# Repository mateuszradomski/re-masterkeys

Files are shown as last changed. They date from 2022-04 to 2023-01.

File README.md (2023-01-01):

This repository aims to document the reverse engineering effort behind Cooler Master Masterkeys keyboards.

As a result you can:
 - re-flash the original firmware with a different key map
 - flash QMK [see here](https://github.com/mateuszradomski/qmk_masterkeys)
 - write your own bare metal firmware

Currently **only the Masterkeys Pro S White** is tested and proved working.
If you have any other keyboard from this series you can contribute by expanding the current knowledge.
Checkout the work of [hansemro](https://github.com/hansemro) in the Issues Tab right now.
Everything from this point on is written from the point of view of the Pro S White.

# Hardware specification

The keyboard contains three ICs:

 - Holtek HT32F52352 ARM MCU (the chip is probably mislabeled as HT50F52352 [see](https://github.com/pok3r-custom/pok3r_re_firmware/issues/32))
 - GigaDevice GD25Q40C 4MB SPI Flash
 - Macroblock MBIA043GP LED Driver

The MCU is a 48MHz ARM Cortex-M0+ chip.
[ChaoticEnigma](https://github.com/ChaoticEnigma) has already compiled a list of documentation PDFs and examples from Holtek in the [pok3r_re_firmware](https://github.com/pok3r-custom/pok3r_re_firmware) repo.
You are going to see a lot of references to the work of [ChaoticEnigma](https://github.com/ChaoticEnigma), without his RE efforts this probably would not be possible.
Thanks!
The MCU is inside a 64 pin package and almost all of them are used.
The board contains a JTAG connector that will be crucial in flashing your own firmware.
From the start it's locked but you can unlock it which allows you to read/write to it freely.
You can find the pin-out for the JTAG in the schematic stored in the `kicad` directory.
Ground is the pin closest to the MCU, while VDD is the furthest pin from the MCU.
If you feel unsure about it, you can always use a multimeter to confirm.

The SPI is used in the original firmware to store profiles - accessed via `FN + 1-4`.
You can use it in your own firmware if you need, the documentation is inside the `docs` directory, but you can easily find it on the internet.

The LED driver has 16 output pins, it's used in combination with 8 pins from the MCU to form a matrix.
Positive voltage is emitted by the driver to a particular column and the LED will glow if the row has been pulled low by the MCU.
Because of the amazing work done by [hansemro](https://github.com/hansemro) in RE of lighting for Pro S RGB which shares the same chip with Pro S White, lighting is now supported in QMK.
The documentation for the chip does not really exist but many things are similar across the chips, for general hang of how the chip work checkout the documentation to MBI5040 in the docs folder.
And for special instructions that are supported by the MBIA043GP see the accompanying .md file, information there is copied from hansemro's issue for the Pro S RGB model.

# Original firmware

_I do not take responsibility for any damages that you might make to your keyboard while trying to anything with it_

From the three Pro X White variants only Pro M and Pro L have firmware upgrades.
This makes the process of recovering the original Pro S White firmware hard.
Cooler Master hosts these updates [here for Pro M](http://update.coolermaster.com/masterkeys-pro-m-white/masterkeys-pro-m-white-v1.06.zip) and [here for Pro L](update.coolermaster.com/masterkeys-pro-l-white/masterkeys-pro-l-white-v1.08.zip).
Using the [pok3rtool](https://github.com/pok3r-custom/pok3rtool) you can extract the firmware from these updaters which has [already been discussed in this issue](https://github.com/pok3r-custom/pok3rtool/issues/6).

If you plan to flash your own firmware and your bootloader is not currently inside the `binaries` directory, I advise to flash a modified version of the firmware with the flash reading patch.
It's pretty well described in the issue linked above.
After patching and dumping the `bootloader + firmware` you are more or less safe - meaning if you manage to brick your keyboard you can reprogram it using any JTAG debugger or Raspberry Pi, I used the Raspberry Pi Zero which worked a treat.
You if you dumped a bootloader from a different model your contribution is welcomed!

## Pro S White note

Since firmware for this keyboard is not provided by Cooler Master currently it's not possible to re-flash back to stock firmware.
You can use Pro L firmware and modify - using a hex editor - the key map which brings your keyboard back to a working condition.
As a side effect **lighting no longer works**!
If you want to modify the key map it's defined as an array of USB-HID codes starting at offset `0x618d` in the Pro L firmware file.
In the `binaries` directories I attached a Pro L firmware with the Pro S keymap - Caps is Escape right now.

# Flashing

## The role of the original bootloader

The keyboard has essentially two programs on it: bootloader and firmware.
Firmware is what is running on it most of the time, everything from lighting to profiles are implemented there.
The thing I refer to as a bootloader is an in-application programming (IAP) program.
It allows you to reprogram the firmware without having to use the JTAG connector every time.
So if you want to quickly iterate over firmwares I'd suggest leaving the bootloader be.

You have two options of flashing:

## Erase the original bootloader and program every time using the JTAG

If you want to need more flash memory you can remove the original bootloader which takes around 12.5Kb (~10% of the flash).
It's almost never the case you want to do this so move to the second option.

## Use the bootloader to write the new firmware using the pok3rtool

The already mentioned [pok3rtool](https://github.com/pok3r-custom/pok3rtool) is perfect for flashing the new firmware.

If you stick to the original firmware and only make small tweaks it will put the keyboard in to the bootloader mode for you and reprogram it.

On the other hand if you use QMK you can set your keyboard so that it will boot into the bootloader.
This is already done in the linked QMK, just press `LShift + RShift + B`.
Your keyboard will boot into the bootloader and await being programmed.
You can confirm this by watching the output `dmesg`, it should appear as a `Cooler Master HID-IAP`.
When it's ready flash the firmware.

## Example flashing using the bootloader

 - Download [pok3rtool](https://github.com/pok3r-custom/pok3rtool)
 - Apply the patch referencing your keyboard from `patches`
 - Compile the tool
 - Run `sudo ./pok3rtool --ok -t cmpro<s|m|l> flash <version string> <your firmware binary>`
 - Your keyboard is flashed!
 
# Unlocking the MCUs JTAG

[ChaoticEnigma](https://github.com/ChaoticEnigma) already figured this out [here](https://github.com/pok3r-custom/pok3r_re_firmware/wiki/HT32-Unlocking).
His fork of the OpenOCD with the HT32F1xxxx support works with HT32F5xxxx MCUs as well.
Remember that the logic of the keyboard works on `3.3V`!
If you want to be extra careful not to fry anything just connect all cables without VDD and power the keyboard by connecting it to USB.

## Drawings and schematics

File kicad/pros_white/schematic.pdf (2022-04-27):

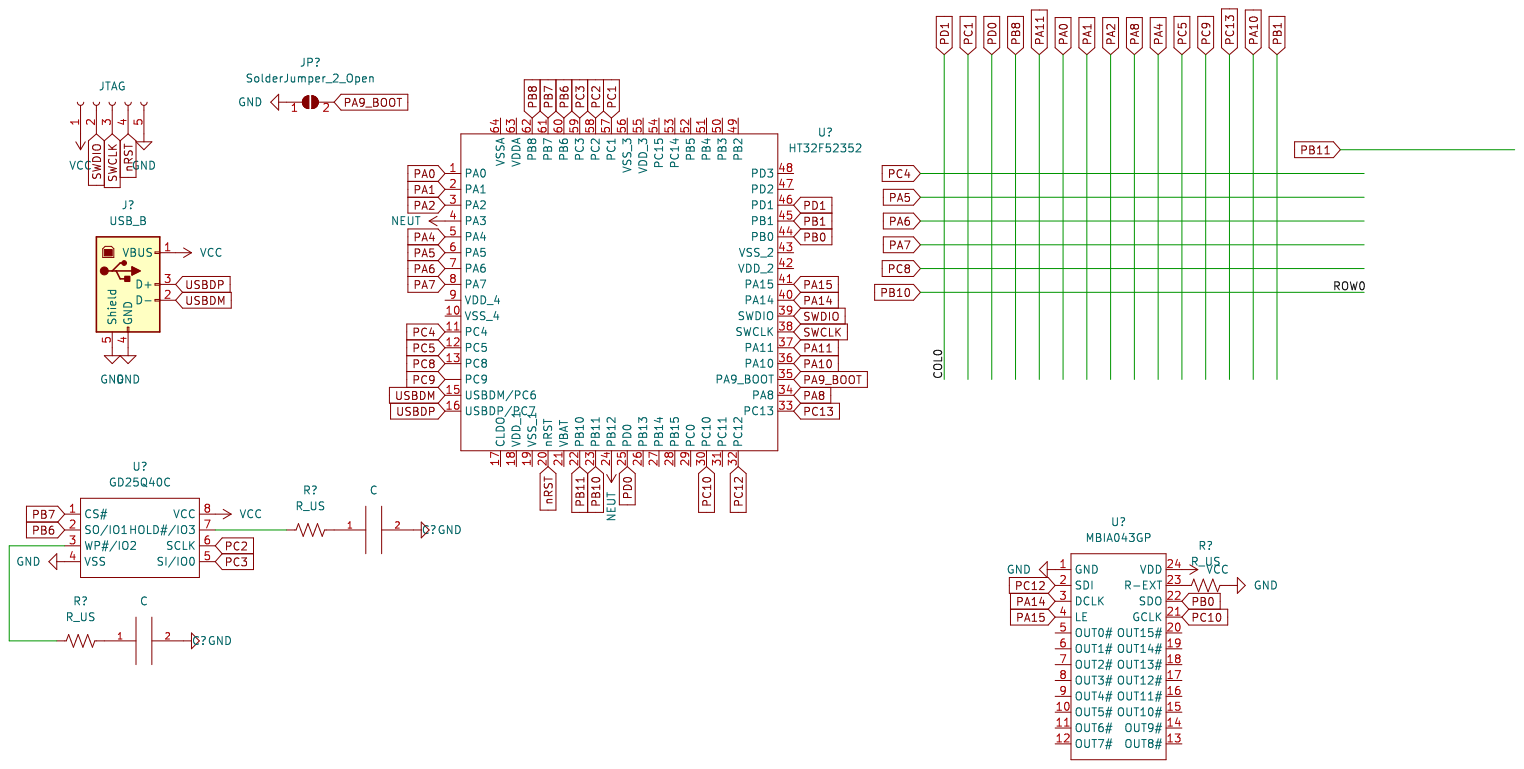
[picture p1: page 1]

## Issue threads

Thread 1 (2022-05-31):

Pro S RGB Support

hansemro, 2022-05-31:
I was unable to find detailed specs anywhere else for this model, so here is what I found:
- Holtek HT32F1654 (Cortex-M3)
- GigaDevice 25Q40CT
- 3x Macroblock MBIA043GP (1 per channel)

CN2 header:
- pin 1: 3v3
- pin 2: SWDIO
- pin 3: SWCLK
- pin 4: nRST
- pin 5: GND

SEL1 header:
- pin 1: BOOT0
- pin 2: GND

SEL2 header:
- pin 1: GND
- pin 2: BOOT1

So far, very similar to POK3R RGB. I will update with more details as I find them.

Tasks:
- [ ] Add photos
- [ ] Add Pro S RGB schematic
- [ ] Access JTAG
- [ ] Try unlocker
- [ ] Dump SPI flash
- [ ] Dump bootloader and firmware
- [ ] Write to flash
- [ ] TODO

hansemro, 2022-06-01:
Raspberry Pi 4 : ProS
- pin 9 : GND
- pin 12 : nRST
- pin 18 : SWDIO
- pin 22 : SWCLK

Rebased openocd-ht32 with latest commits to fix some issues with raspberry pi: https://github.com/hansemro/openocd-ht32/tree/ht32f165x-dev

openocd.cfg:
```
adapter driver bcm2835gpio
adapter speed 1

### for pi4
bcm2835gpio peripheral_base 0xFE000000
bcm2835gpio speed_coeffs 236181 60

## swd_nums <swclk> <swdio>
## Header pins 22 18
bcm2835gpio swd_nums 25 24

## reset: pin 12 on the PI
bcm2835gpio srst_num 18
reset_config srst_only srst_push_pull

## dont forget pin 9 for Ground

transport select swd

set HT32_SRAM_SIZE 0x8000
set HT32_FLASH_SIZE 0x20000

source [find target/ht32f165x.cfg]
```

```
pi@raspberrypi:~ $ sudo openocd
Open On-Chip Debugger 0.11.0+dev-02293-g1f3300cca (2022-06-01-06:21)
Licensed under GNU GPL v2
For bug reports, read
        http://openocd.org/doc/doxygen/bugs.html
trst_only separate trst_push_pull

Info : Listening on port 6666 for tcl connections
Info : Listening on port 4444 for telnet connections
Info : BCM2835 GPIO JTAG/SWD bitbang driver
Info : clock speed 12 kHz
Info : SWD DPIDR 0x2ba01477
Info : [ht32f165x.cpu] Cortex-M3 r2p0 processor detected
Info : [ht32f165x.cpu] target has 6 breakpoints, 4 watchpoints
Info : starting gdb server for ht32f165x.cpu on 3333
Info : Listening on port 3333 for gdb connections
```

hansemro, 2022-06-01:
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

hansemro, 2022-06-02:
Pro S RGB firmware patch: https://github.com/hansemro/re-masterkeys/blob/Pro_S_RGB/binaries/Pro_S_RGB/patch.txt

```
FW offset 0x3400 (?)

    67fa: ff 28           cmp        r0,#0xff
    67fc: 0c d1           bne        0x00006818
    67fe: 68 68           ldr        r0,[r5,#0x4]
    6800: 3c 21           movs       r1,#0x3c
    6802: 31 e0           b          0x00006868
    6804: 00 bf           nop
    6806: 00 bf           nop
    6808: 00 bf           nop
    680a: 00 bf           nop
    680c: 00 bf           nop
    680e: 00 bf           nop
    6810: 00 bf           nop
    6812: 00 bf           nop
    6814: 00 bf           nop
    6816: 00 bf           nop
```

hansemro, 2022-06-02:
Some USB packet captures:

1: Plugging in keyboard
[plug-in.zip](https://github.com/m-radomski/re-masterkeys/files/8823571/plug-in.zip)

2: Firmware upgrade (1.2.2 to 1.2.2) via OEM software
[fw-upgrade.zip](https://github.com/m-radomski/re-masterkeys/files/8823574/fw-upgrade.zip)

hansemro, 2022-06-02:
python script to get current firmware from Pro S:

Dependency: pyusb

get_version.py:
```
#!/usr/bin/env python3

import usb.core
import usb.util

dev = usb.core.find(idVendor=0x2516, idProduct=0x003c)

if dev is None:
    raise ValueError('CM Pro S not found')
else:
    print("CM Pro S found")

if dev.is_kernel_driver_active(1):
    try:
        dev.detach_kernel_driver(1)
        print("kernel driver detached")
    except usb.core.USBERROR as e:
        print(f"Could not detach kernel driver: {e}")
        exit(1)

try:
    usb.util.claim_interface(dev, 1)
    print("Claimed usb device")
except:
    print(f"{e}")
    exit(1)

ver_req = [ 0x01,0x02,0xdf,0xfc,0x00,0x30,0x00,0x00,0x3d,0x30 ]

dev.write(0x04, ver_req)

out = dev.read(0x83, 64)
out = "".join(chr(x) for x in out)
print(f"{out[4:9]}")
```

output:
```
$ python3 get_version.py
CM Pro S found
kernel driver detached
Claimed usb device
1.2.2
```

hansemro, 2022-06-03:
Reset to bootloader: `[0x4,0x1]`
Reset to firmware: `[0x4,0x0]`

hansemro, 2022-06-04:
Analyzing fw-upgrade.pcap from above.

un: unknown
ar: address
ct: count
pd: padding
ed: end

Start writing firmware at 0x3400 in 0x34 byte increments...

```
       write-un-un-ar.ar.ar.ar-ed-ct-pd-pd-_data...
0000   01 01 2a 4b 00 34 00 00 33 34 00 00 _48 27 00 20
0010   55 35 00 00 61 35 00 00 63 35 00 00 65 35 00 00
0020   67 35 00 00 69 35 00 00 00 00 00 00 00 00 00 00
0030   00 00 00 00 00 00 00 00 6b 35 00 00 6d 35 00 00
```

0x34 (52,+0x34) bytes written
expect next data to be written start with 0000 0000 6f35...
next_write_addr: 0x3434

```
0000   01 01 c9 af 34 34 00 00 67 34 00 00 _00 00 00 00
0010   6f 35 00 00 71 35 00 00 73 35 00 00 73 35 00 00
0020   73 35 00 00 73 35 00 00 73 35 00 00 73 35 00 00
0030   73 35 00 00 73 35 00 00 73 35 00 00 73 35 00 00
```

0x34 (+0x68) bytes written
expected next data: 7335 0000 7335 0000 7335 ....
next_write_addr: 0x3468

```
0000   01 01 ae 41 68 34 00 00 9b 34 00 00 _73 35 00 00
0010   73 35 00 00 73 35 00 00 73 35 00 00 73 35 00 00
0020   73 35 00 00 73 35 00 00 73 35 00 00 73 35 00 00
0030   73 35 00 00 73 35 00 00 73 35 00 00 73 35 00 00
```

0x34 (+0x9c) bytes written
next_write_addr: 0x349c

```
0000   01 01 b2 e2 9c 34 00 00 cf 34 00 00 _73 35 00 00
0010   73 35 00 00 73 35 00 00 00 00 00 00 73 35 00 00
0020   73 35 00 00 73 35 00 00 73 35 00 00 73 35 00 00
0030   73 35 00 00 73 35 00 00 73 35 00 00 73 35 00 00
```

0x34 (+0xd0) bytes written
next_write_addr: 0x34d0

```
0000   01 01 e3 0c d0 34 00 00 03 35 00 00 _73 35 00 00
0010   00 00 00 00 00 00 00 00 00 00 00 00 00 00 00 00
0020   e1 37 00 00 8d 38 00 00 73 35 00 00 73 35 00 00
0030   73 35 00 00 73 35 00 00 73 35 00 00 73 35 00 00
```

0x34 (+x01_04) bytes written
next_write_addr: 0x3504

```
0000   01 01 5f 7d 04 35 00 00 37 35 00 00 _73 35 00 00
0010   73 35 00 00 73 35 00 00 73 35 00 00 bd 85 00 00
0020   00 00 00 00 73 35 00 00 73 35 00 00 73 35 00 00
0030   73 35 00 00 73 35 00 00 73 35 00 00 73 35 00 00
```

0x34 (+x01_38) bytes written
next_write_addr: 0x3538

```
0000   01 01 28 9b 38 35 00 00 6b 35 00 00 _73 35 00 00
0010   00 00 00 00 00 00 00 00 00 00 00 00 00 00 00 00
0020   00 00 00 00 73 35 00 00 07 48 80 47 07 48 80 47
0030   07 48 00 47 fe e7 fe e7 fe e7 fe e7 fe e7 fe e7
```

Need help figuring out what the two unknown bytes are.
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
hansemro, 2022-09-09:
Fixed firmware writing with my fork of pok3rtool with https://github.com/hansemro/pok3rtool/commit/11b822daccf6230801e9e4c1574e27bc54f884a1, managed to dump flash from another Pro S RGB, and recover my previously dead board with stock bootloader!

hansemro, 2022-09-14:
Added initial schematic drawing after a few days of tracing: https://github.com/hansemro/re-masterkeys/commit/35a5ebbd49aea75002c9e5f61e1f66275bda403c

hansemro, 2022-10-06:
Added initial QMK support (key switch and USB support only): https://github.com/hansemro/qmk_firmware/tree/prosrgb_dev

hansemro, 2022-10-11:
# MBIA043 RE notes:

These results were discovered from firmware disassembly and testing in QMK.

## Instructions
Instructions are determined by the number of DCLK rising edges while LE is asserted.

For instructions that read data from shift register, the falling edge of LE must occur after the final data entry gets shifted.

### Data Latch: 1 DCLK rising edge

Moves data from shift register to buffer.

### Overall Latch: 2 DCLK rising edges

Sets comparator to value in buffer.

### (Undocumented) Read Configuration: 4 DCLK rising edges

Moves 10-bit configuration data to shift register.

Configuration:
```
  MSB     ...     LSB
0b0_0_0_0_0_0_0_0_1_0 (default)
  | | | | | | | | | `-> counter disable (when 1)
  | | | | | | | | `-> unk1
  | | | | | | | `-> unk2
  | | | | | | `-> unk3
  | | | | | `-> unk4 (cannot be set)
  | | | | `-> unk5 (cannot be set)
  | | | `-> unk6 (cannot be set)
  | | `-> unk7 (cannot be set)
  | `-> unk8
  `-> unk9 (cannot be set)
```

### (Undocumented) Enable Write Configuration: 18 DCLK rising edges

Enables Write Configuration instruction (if it is the next instruction).

### (Undocumented) Write Configuration: 8 DCLK rising edges

Moves data from shift register to (undocumented) configuration register.

hansemro, 2022-10-14:
Dimming test (shortened cycle length to reduce video length) with QMK.

https://user-images.githubusercontent.com/40348686/195756326-3854ea60-c413-4904-a0f4-0d8b56e75f63

hansemro, 2022-10-17:
Per-key lighting on QMK:
https://user-images.githubusercontent.com/40348686/196301393-073a03fa-a6db-4df2-932d-af04cba0297b.mp4

hansemro, 2022-10-24:
Keyboard (with QMK) hardfaults after enabling Flash Memory Security Protection bit (OB_PP[0]).

hansemro, 2022-11-14:
Added a new openocd branch to enable security bits (which will be used to debug lockup when security is enabled): https://github.com/hansemro/openocd-ht32/tree/ht32f165x-security-test

```
> # unlocked keyboard
> halt; ht32f165x check_security 0
[ht32f165x.cpu] halted due to debug-request, current mode: Handler External Interrupt(41)
xPSR: 0x21000039 pc: 0x00000108 msp: 0x20000d18
ht32f165x probe: 128 pages, 0x400 bytes, 0x20000 total
ht32f165x opt byte: ffffffff ffffffff ffffffff ffffffff ffffffff
ht32f165x CPSR: 0xffffffff
ht32f165x OB_CP: 0xffffffff
ht32f165x OB_CK: 0xffffffff
ht32f165x opt byte: ffffffff ffffffff ffffffff ffffffff ffffffff
ht32f165x check_security complete

# relocking keyboard
> halt; ht32f165x enable_security 0
[ht32f165x.cpu] halted due to debug-request, current mode: Handler External Interrupt(41)
xPSR: 0x01000039 pc: 0x00000134 msp: 0x20000d28
ht32f165x probe: 128 pages, 0x400 bytes, 0x20000 total
ht32f165x opt byte: ffffffff ffffffff ffffffff ffffffff ffffffff
ht32f165x programming word 0x0000 @ 0x1ff00000
ht32f165x programming word 0xffffffff @ 0x1ff00004
ht32f165x programming word 0xffffffff @ 0x1ff00008
ht32f165x programming word 0xffffffff @ 0x1ff0000c
ht32f165x programming word 0xfffffffe @ 0x1ff00010
ht32f165x programming word 0xfffffffb @ 0x1ff00020
ht32f165x Security will be set on reset
ht32f165x enable security complete

# confirming keyboard is locked
> halt; ht32f165x check_security 0
[ht32f165x.cpu] halted due to debug-request, current mode: Handler HardFault
xPSR: 0x01000003 pc: 0x00000124 msp: 0x20000d28
ht32f165x probe: 128 pages, 0x400 bytes, 0x20000 total
ht32f165x opt byte: 0000 0000 0000 0000 0000
ht32f165x CPSR: 0xfffffffc
ht32f165x OB_CP: 0x0000
ht32f165x OB_CK: 0x0000
ht32f165x opt byte: 0000 0000 0000 0000 0000
ht32f165x check_security complete
```

hansemro, 2022-11-14:
While keyboard is locked, things you can do in openocd:
- use `reset halt` command to halt MCU in working state before it faults.
- set registers (e.g. `reg <r0|r1|...|pc> <value>`) and `step` through instructions while in working state.
- read registers with `reg` command

Some things you cannot do while locked:
- Use load instructions to read data from internal program flash (DCODE). Load instructions in firmware will read in 0 (while debugger is attached). Loading from SRAM (0x20000000) works just fine.

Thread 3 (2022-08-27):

Pro L RGB Support

hansemro, 2022-08-27:
HW info: TODO

Tasks:
- [ ] Add photos
- [ ] Add schematic
- [ ] Write firmware patch
- [ ] Patch pok3rtool
    - [ ] Add Pro L RGB VID/PID/IPID
        - [ ] firmware mode : 2516:0047
        - [ ] bootloader mode : 2516:0046
    - [ ] version command
    - [ ] setversion command
    - [ ] reboot command
    - [ ] bootloader command
    - [ ] info command
    - [ ] dump command
    - [ ] flash command
    - [ ] wipe command
- [ ] Working firmware patch
- [ ] Dump firmware
- [ ] Dump bootloader
- [ ] Dump SPI flash

hansemro, 2022-08-27:
Info command output:
```
$ ./pok3rtool -t prolrgb info --ok
Opened MasterKeys Pro L RGB
3000  12000000 56003100 2e003000 38002e00 30003000 0000ffff ffffffff ffffffff | ....V.1...0.8...0.0.............
3020  ffffffff ffffffff ffffffff ffffffff ffffffff ffffffff ffffffff ffffffff | ................................
3040  ffffffff ffffffff ffffffff ffffffff ffffffff ffffffff ffffffff ffffffff | ................................
3060  ffffffff ffffffff ffffffff ffffffff ffffffff ffffffff 04008000 00030100 | ................................
3080  41000000 ffffffef 01000000 00000000 d9046701 ffffffff ffffffff ffffffff | A.................g.............
30a0  ffffffff ffffffff ffffffff ffffffff a55a1c00                            | .................Z..    
Version String: V1.08.00
a: 00800004
Version: 00010300
c: 00000041
d: efffffff
e: 00000001
f: 00000000
VID/PID: 04d9 0167
h: 001c5aa5
READ_400
0000  04000000 00000000 16254600 00000404 ffffffff 01000000 ffffffff 2e000000 | .........%F.....................
0020  0002e700 00024b42 30313933 00000000 ffffffff                            | ......KB0193........    
READ_3c00
0000  04000200                                                                | ....                    
true
```

hansemro, 2022-08-27:
Setting custom version:
```
$./pok3rtool -t prolrgb version
Opened MasterKeys Pro L RGB
Version: V1.08.00
$ ./pok3rtool -t prolrgb --ok setversion V1.07.FF
Opened MasterKeys Pro L RGB
Old Version: V1.08.00
Reset to Bootloader
Writing Version: V1.07.FF
1
Reset to Firmware
true
$ ./pok3rtool -t prolrgb version
Opened MasterKeys Pro L RGB
Version: V1.07.FF
```

hansemro, 2022-08-27:
Just realized that I have White model lol. Didn't even bother to check if it was RGB.

hansemro, 2022-08-27:
Modified SVD: [HT32F52342_52.svd.zip](https://github.com/mateuszradomski/re-masterkeys/files/9438735/HT32F52342_52.svd.zip)

SVD Source: https://web.archive.org/web/20220827045212/https://mcu.holtek.com.tw/pack/Holtek.HT32_DFP.1.0.41.pack

hansemro, 2022-08-28:
I was able to dump bootloader and firmware with this updated patch:

```
FW offset 0x3200

        6260: ff 28           cmp        r0,#0xff
        6262: 05 d1           bne        0x00006270
        6264: 68 68           ldr        r0,[r5,#0x4]
        6266: 3c 21           movs       r1,#0x3c
        6268: 30 e0           b          0x000062cc
        626a: 00 bf           nop
        626c: 00 bf           nop
        626e: 00 bf           nop
```

Flashing patched firmware with patched pok3rtool worked without a hitch:
```
$ git clone https://github.com/hansemro/re-masterkeys -b Pro_L_White
$ cd re-masterkeys/binaries/Pro_L_White
$ pok3rtool -t prolwhite flash V1.09.00 ProLW_fw_patched.bin --ok
Opened MasterKeys Pro L White
Update Firmware: ProLW_fw_patched.bin
Reset to Bootloader
Current Version: V1.08.00
Firmware CRC D: 2519525c
Firmware CRC E: 4edec2ee
crc 3d198f21
sum e3f6fbbb
Current CRC: 3d198f21
Erase...
Write...
crc 4edec2ee
sum e400cc6d
New CRC: 4edec2ee
Writing Version: V1.09.00
Reset to Firmware
true
$ pok3rtool -t prolwhite dump bl_fw_dump.bin --ok
Opened MasterKeys Pro L White
Dump Flash
Out: bl_fw_dump.bin, 65520 bytes
```

hansemro, 2022-10-27:
Added initial schematic drawing in KiCad: https://github.com/hansemro/re-masterkeys/blob/09ef6fb995ffd5092bbb7bde4db733936313a8f0/kicad/prol_white/25L4006E.kicad_sym

hansemro, 2022-10-28:
WIP QMK with MBI5042 demo (source coming soon):

https://user-images.githubusercontent.com/40348686/198546031-cec75729-407e-4fda-baa9-234bb24be269.mp4

@mateuszradomski Were you able to map led pins on Pro S White? This should be easy to replicate on Pro S White with MBIA043 drivers that I wrote for Pro S RGB.

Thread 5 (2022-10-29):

Pro M White Support

hansemro, 2022-10-29:
HW info:
- Holtek HT32F52352 (Cortex-M0+)
- Macroblock MBI5042GP LED Driver

Tasks:
- [ ] Add photos
- [ ] Add schematic
- [ ] Write firmware patch
    - [ ] Find FW offset: 0x3200 (based off VTOR offset)
- [x] Patch pok3rtool: WIP fork https://github.com/hansemro/pok3rtool/tree/cooler-master-dev
    - [x] Add Pro M White VID/PID/IPID
        - [x] firmware mode : 2516:0048
        - [x] bootloader mode : 2516:0049
    - [x] version command
    - [x] setversion command
    - [x] reboot command
    - [x] bootloader command
    - [x] info command
        - [x] get version
        - [x] Holtek VID/PID: 04d9:0167
    - [x] dump command
    - [x] flash command
    - [ ] wipe command
- [ ] Working firmware patch
- [x] Dump firmware
    - [ ] Annotate V1.06.00 FW: WIP @ https://github.com/hansemro/pok3r_re_firmware/tree/cmpromwhite/disassemble/cmpromwhite/v160
- [x] Dump bootloader @ 0x0
    - [ ] Annotate: WIP https://github.com/hansemro/pok3r_re_firmware/tree/cmpromwhite/disassemble/cmpromwhite/builtin
- [ ] Dump SPI flash
- [ ] QMK port
    - [ ] working key matrix
    - [ ] nKey Rollover
    - [ ] working USB
    - [ ] FN+Esc to reboot to bootloader
    - [ ] MBI5042 RGB matrix driver
        - [ ] init
        - [ ] flush
        - [ ] set_color
        - [ ] set_color_all
    - [ ] SPI flash driver

hansemro, 2023-03-06:
```
$ ht32-dfu-tool -w info
Waiting for device...
Claimed interface
Getting device info...
Model: HT32F52352
Version: v101
Page size: 512 B
Flash size: 130560 B
Flash security: true
Option byte protection: true
Page protection: 0xfffff000 0xffffffff 0xffffffff 0xffffffff
```

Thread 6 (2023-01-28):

Pro L RGB Support

hansemro, 2023-01-28:
HW info:
- Holtek HT32F1654 (Cortex-M3)
- MXIC 25L4006E 4Mbit SPI Flash
- 3x Macroblock MBI5042GP LED Driver (1 per channel)

Tasks:
- [ ] Add photos
- [ ] Add schematic
- [ ] Write firmware patch
    - [ ] Find FW offset
- [ ] Patch pok3rtool
    - [ ] Add Pro L RGB VID/PID/IPID
        - [ ] firmware mode : 2516:003b
        - [ ] bootloader mode : 2516:003a
    - [ ] version command
    - [ ] setversion command
    - [ ] reboot command
    - [ ] bootloader command
    - [ ] info command
        - [ ] get version
    - [ ] dump command
    - [ ] flash command
    - [ ] wipe command
- [ ] Working firmware patch
- [ ] Dump firmware
    - [ ] Annotate FW
- [ ] Dump bootloader @ 0x0
    - [ ] Annotate
- [ ] Dump bootrom @ 0x1f000000
    - [ ] Annotate
- [ ] Dump SPI flash
- [ ] QMK port
    - [ ] working key matrix
    - [ ] nKey Rollover
    - [ ] working USB
    - [ ] Hold Esc while plugging in usb to reboot to bootloader
    - [ ] FN+Esc to reboot to bootloader
    - [ ] MBI5042 RGB matrix driver
        - [ ] init
        - [ ] flush
        - [ ] set_color
        - [ ] set_color_all
    - [ ] SPI flash driver

hansemro, 2023-01-28:
ISP info:

```
$ ./pok3rtool -t isp info --ok
Opened Holtek ISP USB
0000  54160001 00000004 3f003f00 ffffffff fcffffff ffffffff ffffffff ffffffff | T.......?.?.....................
0020  f9efffff ffffffff ffffffff ffffffff ffffffff 08910000 ffffffff ffffffff | ................................
ISP version: v100
model: HT32F1654
page size in bytes: 1024
flash size in bytes: 64512
flash security: true
option byte protection: true
flash page protection: fffff000 ffffffff ffffffff ffffffff
status: 2
true
```

Also has vulnerable ISP.

hansemro, 2023-01-28:
QMK with MBI5042 RGB matrix driver:
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

hansemro, 2023-01-28:
Pro L RGB and Pro L White share the same key and LED matrices, so I had an easier time porting QMK.

hansemro, 2023-01-28:
Interestingly Pro L RGB's IAP bootloader does not allow read command even for checking application firmware version. I will update my fork of pok3rtool soon to workaround this quirk.

hansemro, 2023-01-30:
Experimental pok3rtool fork that uses checkFlash command for validation (instead of readFlash): https://github.com/hansemro/pok3rtool/commits/cmprolrgb-test
- This fork works for both Pro L RGB and Pro S RGB.
- Relies on GET_REPORT control transfer support to check whether the checkFlash command(s) passed or failed.

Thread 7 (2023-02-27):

Pro M RGB Support

hansemro, 2023-02-27:
HW info:
- Holtek HT32F1654 (Cortex-M3)
- GigaDevice 25Q40CT 4Mbit SPI Flash
- 3x Macroblock MBIA043GP (1 per channel)

Tasks:
- [ ] Add photos
- [ ] Add schematic
- [ ] Write firmware patch
    - [x] Find FW offset: 0x3400
- [ ] Patch pok3rtool
    - [ ] Add Pro L RGB VID/PID/IPID
        - [ ] firmware mode : 2516:004d
        - [ ] bootloader mode : 2516:004e
    - [ ] version command
    - [ ] setversion command
    - [ ] reboot command
    - [ ] bootloader command
    - [ ] info command
        - [ ] get version
    - [ ] dump command
    - [ ] flash command
    - [ ] wipe command
- [ ] Working firmware patch
- [ ] Dump firmware
    - [ ] Annotate FW
- [ ] Dump bootloader @ 0x0
    - [ ] Annotate
- [ ] Dump SPI flash
- [ ] QMK port
    - [ ] working key matrix
    - [ ] nKey Rollover
    - [ ] working USB
    - [ ] Hold Esc while plugging in usb to reboot to bootloader
    - [ ] FN+Esc to reboot to bootloader
    - [ ] MBIA043 RGB matrix driver
        - [ ] init
        - [ ] flush
        - [ ] set_color
        - [ ] set_color_all
    - [ ] SPI flash driver

hansemro, 2023-03-06:
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

Finally managed to port QMK for Pro M White + RGB! These two were very hard to get my hands on, especially the RGB variant.

hansemro, 2023-03-06:
The primary things holding me back from upstreaming my ports:

1. Fixing intermittent LED flickering on some keyboards
2. Writing a generic MBI driver that supports various configurations
    - Experimenting with configurable channels: https://github.com/hansemro/qmk_firmware/blob/76a72063eaaa59dcc0c7d5ff0f437a273d30f332/keyboards/masterkeys/promrgb/mbia043.c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
    - Need to look into ROW/COL iterator
    - Software timer fallback for PWM and timer routine?
    - Need to better understand how PWM and timer frequency relate to frame rate.
3. Writing an open source bootloader replacement with dfu-util compatibility
    -  (An incomplete demo exists in ChibiOS-Contrib demos)
    - One that avoids jumping to an empty region of flash and halting would be nice.
    - ISP is always available to update bootloader or return to stock
    - Should allow firmware to reboot to DFU mode similar to IAP.

hansemro, 2023-03-12:
https://github.com/hansemro/ht32_usb_dfu partially accomplishes 3 but does not currently avoid jumping to empty regions of flash. If the device does manage to get locked up, just short BOOT0 to ground and reset to reach DFU mode.

hansemro, 2024-01-16:
Resolved flickering (1) for POK3R RGB by leveraging double buffering in https://github.com/hansemro/qmk_firmware/commit/06a38cd54c2c9ea3d95eee83a7f3e33ef9c509a2, where back buffer is used by rendering tasks and the front buffer is used for flushing completed color data to MBI buffers.

Plecra, 2024-02-03:
Hi there! I have a stock Pro M RGB. Before I start tinkering with anything, are there any dumps that would be useful for the RE work? I see there's a TODO on dumping the spi flash.

Plecra, 2024-02-03:
I've been having a look at the install instructions - is there no way to install the custom FW with the stock update mechanism? I'm not looking forward to ripping the feet off my keyboard :P

hansemro, 2024-02-03:
> are there any dumps that would be useful for the RE work? I see there's a TODO on dumping the spi flash.

SPI flash dumps are not particularly important unless you want to fully RE the stock firmware and make sense of the data written/read from external flash. It may also be useful for restoring from backup.

Most of the pending RE work was found to not be necessary after RE'ing Pro S RGB and Pro L White models.

> have you dumped firmware from any of the pro m rgb update binaries?

Yes, the trick here is to extract FWUpdate.exe from `masterkeys_pro_m_vX.XX.exe/bin/Setup/File/FWUpdate/`. You can use 7z to extract this file. Afterwards, you should be able to use pok3rtool to pull the application firmware binary.

> is there no way to install the custom FW with the stock update mechanism? I'm not looking forward to ripping the feet off my keyboard :P

Unfortunately, no other way has been found.

For disassembly, you only need to partially lift the left side of the rubber feet (with a tweezer) to expose the screw. For Pro M RGB, you only need to do this for the two upper pads (furthest away from you).

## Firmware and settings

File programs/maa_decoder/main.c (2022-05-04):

#include <stdio.h>
#include <assert.h>
#include <stdint.h>
#include <string.h>
#include <stdlib.h>
#include <wchar.h>
#include <ctype.h>

#include "converter.c"

#define ARRAY_LEN(x) (sizeof(x)/sizeof(x[0]))

uint8_t scratch_buffer[8192];

uint32_t maav101_crc32s[] = {
    0x5018a455,
    0xa3606ef9
};

uint32_t reverse_u32(uint32_t x) {
    x = ((x & 0x55555555) <<  1) | ((x >>  1) & 0x55555555);
    x = ((x & 0x33333333) <<  2) | ((x >>  2) & 0x33333333);
    x = ((x & 0x0F0F0F0F) <<  4) | ((x >>  4) & 0x0F0F0F0F);
    x = (x << 24) | ((x & 0xFF00) << 8) | ((x >> 8) & 0xFF00) | (x >> 24);
    return x;
}

unsigned int crc32(uint8_t *data, uint32_t len) {
    uint32_t crc = 0xFFFFFFFF;

    for(uint32_t i = 0; i < len; i++)
    {
        uint32_t byte = reverse_u32(data[i]);
        for (int j = 0; j <= 7; j++)
        {
            if ((int)(crc ^ byte) < 0) {
                crc = (crc << 1) ^ 0x04C11DB7;
            } else {
                crc = crc << 1;
            }

            byte = byte << 1;
        }
    }

    return reverse_u32(~crc);
}

bool inside_array(uint32_t value, uint32_t *array, uint32_t len)
{
    for(uint32_t i = 0; i < len; i++)
    {
        if(array[i] == value) {
            return true;
        }
    }

    return false;
}

// All of decode/encode code is referenced from here
// https://github.com/pok3r-custom/pok3rtool
void decode_data(uint8_t *data, uint32_t len)
{
    for(uint32_t i = 4; i < len; i += 5)
    {
        uint8_t a = data[i-4];
        uint8_t b = data[i];
        data[i-4] = b;
        data[i] = a;
    }

    for(uint32_t i = 1; i < len; i += 2)
    {
        uint8_t d = data[i-1];
        uint8_t b = data[i];
        data[i-1] = b;
        data[i] = d;
    }

    for(uint32_t i = 0; i < len; i++)
    {
        data[i] = (((data[i] - 7) << 4) + (data[i] >> 4)) & 0xFF;
    }
}


void xor_decode_encode(uint8_t *data, uint32_t len){
    static const uint32_t xor_key[] = {
        0xe7c29474,
        0x79084b10,
        0x53d54b0d,
        0xfc1e8f32,
        0x48e81a9b,
        0x773c808e,
        0xb7483552,
        0xd9cb8c76,
        0x2a8c8bc6,
        0x0967ada8,
        0xd4520f5c,
        0xd0c3279d,
        0xeac091c5,
    };

    uint32_t *words = (uint32_t *)data;
    for(uint32_t i = 0; i < len / 4; i++){
        words[i] = words[i] ^ xor_key[i % 13];
    }
}

void decode_firmware_packet(uint8_t *data, uint32_t num){
    const uint8_t swap_key[] = {
        0,1,2,3,
        1,2,3,0,
        2,1,3,0,
        3,2,1,0,
        3,1,0,2,
        1,2,0,3,
        2,3,1,0,
        0,2,1,3,
    };

    static const uint32_t xor_key[] = {
        0x55aa55aa,
        0xaa55aa55,
        0x000000ff,
        0x0000ff00,
        0x00ff0000,
        0xff000000,
        0x00000000,
        0xffffffff,
        0x0f0f0f0f,
        0xf0f0f0f0,
        0xaaaaaaaa,
        0x55555555,
        0x00000000,
    };

    uint32_t *words = (uint32_t*)data;
    for(int i = 0; i < 13; ++i){
        words[i] = words[i] ^ xor_key[i];
    }

    uint8_t f = (num & 7) << 2;
    for(int i = 0; i < 52; i+=4){
        uint8_t a = data[i + swap_key[f + 0]];
        uint8_t b = data[i + swap_key[f + 1]];
        uint8_t c = data[i + swap_key[f + 2]];
        uint8_t d = data[i + swap_key[f + 3]];

        data[i + 0] = a;
        data[i + 1] = b;
        data[i + 2] = c;
        data[i + 3] = d;
    }
}

void decode_firmware(uint8_t *data, uint32_t len){
    uint32_t count = 0;
    for(uint32_t offset = 0; offset < len; offset += 52, count++)
    {
        if(count >= 10 && count <= 100) {
            decode_firmware_packet(data + offset, count);
        }
    }
}

const char *utf16_to_utf8_scrachted(char *str, int max_len)
{
    size_t output_len = sizeof(utf8_t) * utf16_to_utf8((const utf16_t *)str, max_len / sizeof(utf16_t), NULL, 0);
    utf16_to_utf8((const utf16_t *)str, max_len / sizeof(utf16_t), scratch_buffer, output_len / sizeof(utf8_t));
    return scratch_buffer;
}

void decode_maav101(FILE *exe, char *buff, const char *output_filename) {
    int32_t strings_len = 0x4bc;
    fseek(exe, -strings_len, SEEK_END);
    fread(buff, 1, strings_len, exe);

    decode_data(buff, strings_len);

    uint32_t vendor_offset = 0x10;
    uint32_t product_offset = 0x218;
    uint32_t version_offset = 0x461;
    uint32_t signature_offset = 0x4af;

    printf("Vendor:    %s\n", utf16_to_utf8_scrachted(buff + vendor_offset, strings_len - vendor_offset));
    printf("Product:   %s\n", utf16_to_utf8_scrachted(buff + product_offset, strings_len - product_offset));
    printf("Version:   %s\n", buff + version_offset);
    printf("Signature: %s\n", buff + signature_offset);

    uint32_t fw_len_offset = 0x420;
    uint32_t fw_layout_offset = 0x424;

    uint32_t fw_len = *(uint32_t *)(buff + fw_len_offset);
    printf("FW Length: %u\n", fw_len);
    printf("FW Layout: %s\n", utf16_to_utf8_scrachted(buff + fw_layout_offset, strings_len - fw_layout_offset));

    int32_t fw_start = strings_len + fw_len;
    printf("FW offset: 0x%x\n", fw_start);

    fseek(exe, -fw_start, SEEK_END);
    fread(buff, 1, fw_len, exe);
    fclose(exe);

    decode_data(buff, fw_len);
    decode_firmware(buff, fw_len);

    FILE *out = fopen(output_filename, "wb");
    assert(out);
    fwrite(buff, fw_len, 1, out);

    fclose(out);
}

int main(int argc, char **argv)
{
    if(argc != 3) {
        printf("Usage: %s <FWupdate.exe> <output.bin>\n", argv[0]);
        return 0;
    }

    const char *filename = argv[1];
    const char *output_filename = argv[2];
    FILE *exe = fopen(filename, "rb");
    assert(exe);
    fseek(exe, 0, SEEK_END);
    int file_len = ftell(exe);

    uint8_t *buff = malloc(file_len);
    memset(buff, 0, file_len);

    fseek(exe, 0, SEEK_SET);
    fread(buff, 1, file_len, exe);
    uint32_t crc = crc32(buff, file_len);
    printf("crc32: 0x%08x\n", crc);

    if(inside_array(crc, maav101_crc32s, ARRAY_LEN(maav101_crc32s))) {
        decode_maav101(exe, buff, output_filename);
    } else {
        printf("Didn't recognized that file\n");
    }

    return 0;
}
